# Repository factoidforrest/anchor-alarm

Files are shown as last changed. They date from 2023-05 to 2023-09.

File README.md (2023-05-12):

# Anchor Alarm

This is a DIY anchor alarm. An anchor alarm is a device that beeps if you take it further than the set distance from where you turned it on, to tell you if your anchor is dragging and you need to wake up before you run aground.

It is designed to run on the Esp32.

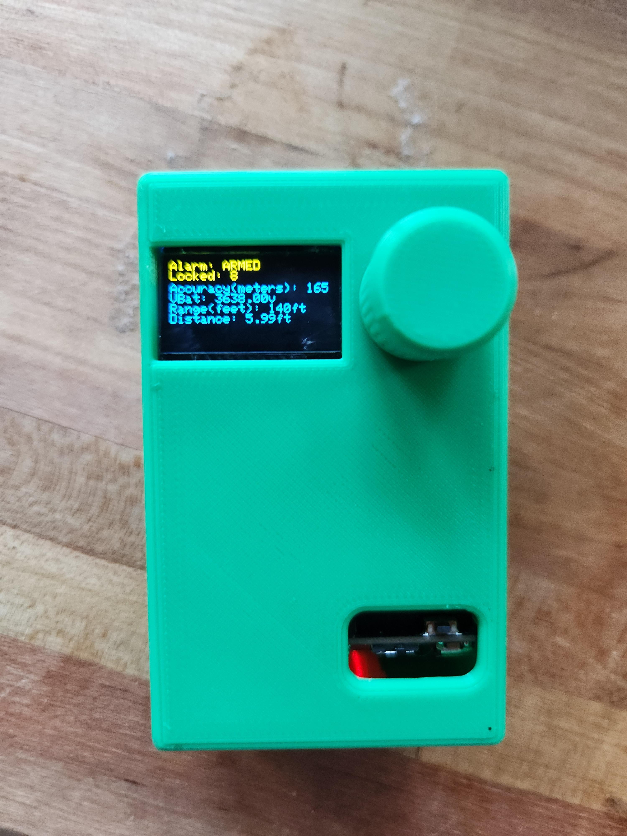
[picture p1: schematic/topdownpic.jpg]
top down pic of the thing in a case


## Hardware

* Mainboard: I ran it on the Esp32-c3 LilyGo OI plus, which is a compact form factor esp32 with an integrated battery slot and USB-C charging. This project could easily be adapted to other boards.

* GPS: I used a compact neo-8m GPS but this could be adapted to virtually any GPS with no code change. Anything supported by tinygpsplus

* Display 1306 .96in display

* Rotary encoder: Just about any with a button will do. 

* A buzzer. I used a magnetic, non self-oscillating buzzer. Small ones are better because they don't overpower the board and require other electronics like flyback diodes. You could also use a breakout board based buzzer, with those diodes incorporated. That would probably be safer for the esp32 and perhaps even louder. The small buzzer I used is just loud enough to be useful, but could easily be drowned out by, say, a loud fan.

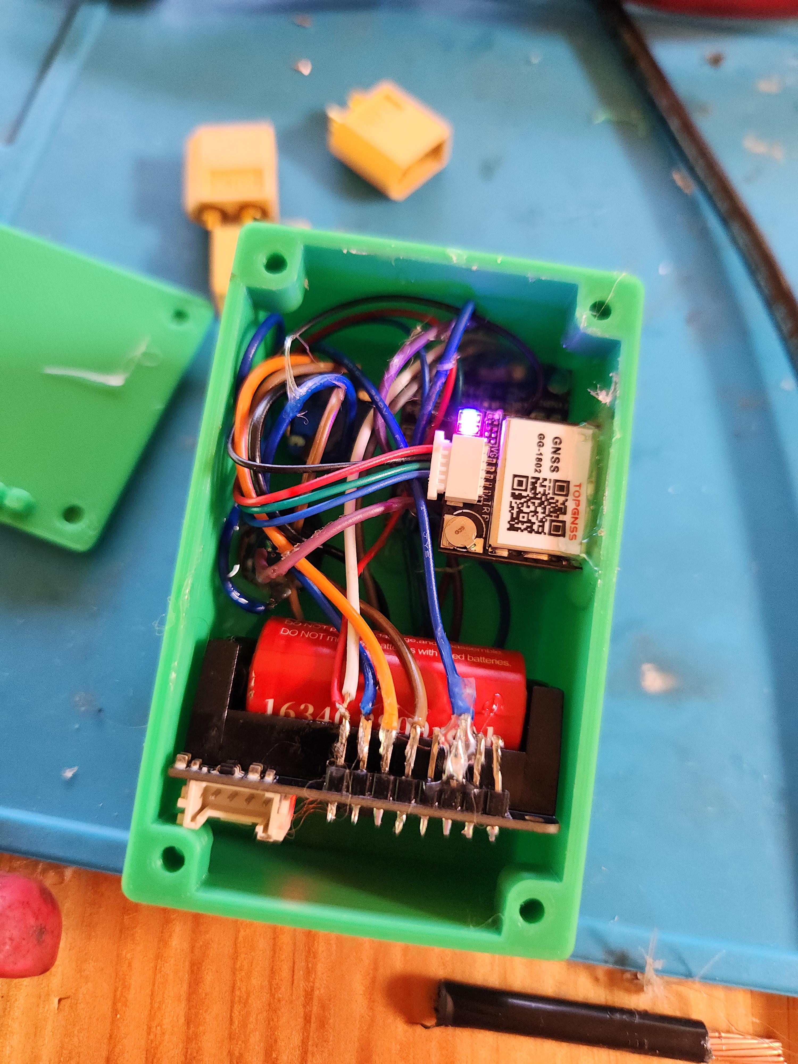
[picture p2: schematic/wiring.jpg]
wiring pic


## 3d Printed Case

If you match the above hardware including the mainboard, you can use my 3d printed case. STL files are in the repo root.

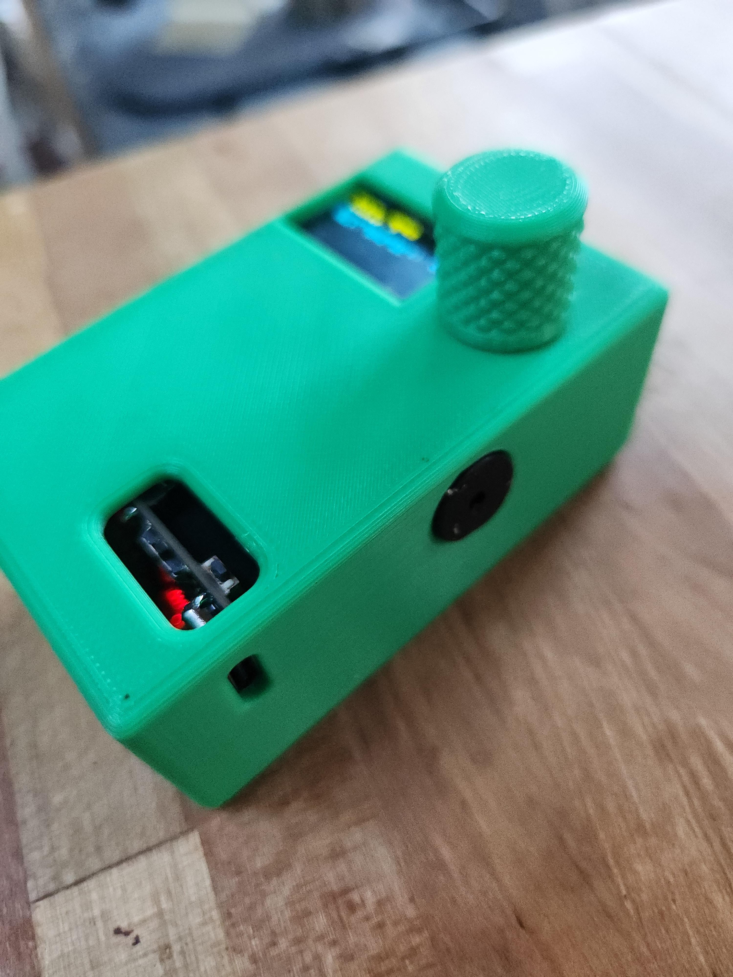
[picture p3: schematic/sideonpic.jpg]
case pic


## Software
Software has over-the-air update support: it creates a public wifi network for five minutes after boot. Hit 192.168.4.1/update to load new .bin firmware fil.

The device will alarm if it runs out of battery, loses the lock for over 10 seconds, or loses communications with the GPS.  

Only token attempts have been made to improve battery life.  It could probably be improved significantly by putting the GPS/esp32 to sleep for appropriate intervals, but that's easier said than done. It appears to only last about 5 hours at present, and so should be plugged in overnight to your phone charger on the boat.

See src/main.cpp for the sketch. Other files are simply tests/ scratchpads I used for debugging. There's also a lot of extra files in here because this was forked from the LilyGo sample project, since this board is nonstandard and needs a lot of custom stuff for the firmware to compile. Standard esp32s wont need that, you can just take the main.cpp sketch file.

### Compilation

This project is compiled by platformio. It will handle all library fetching. Change the board target if you're using a different esp32 version or 8266.

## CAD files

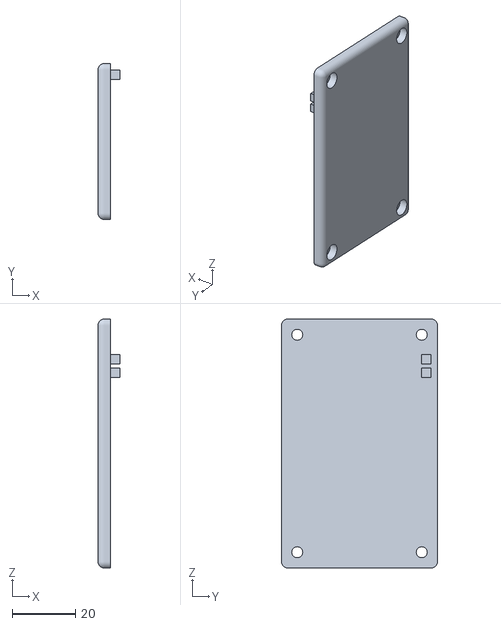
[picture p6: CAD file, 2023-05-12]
bottomlidwider.stl
7.00 x 49.5 x 79.0

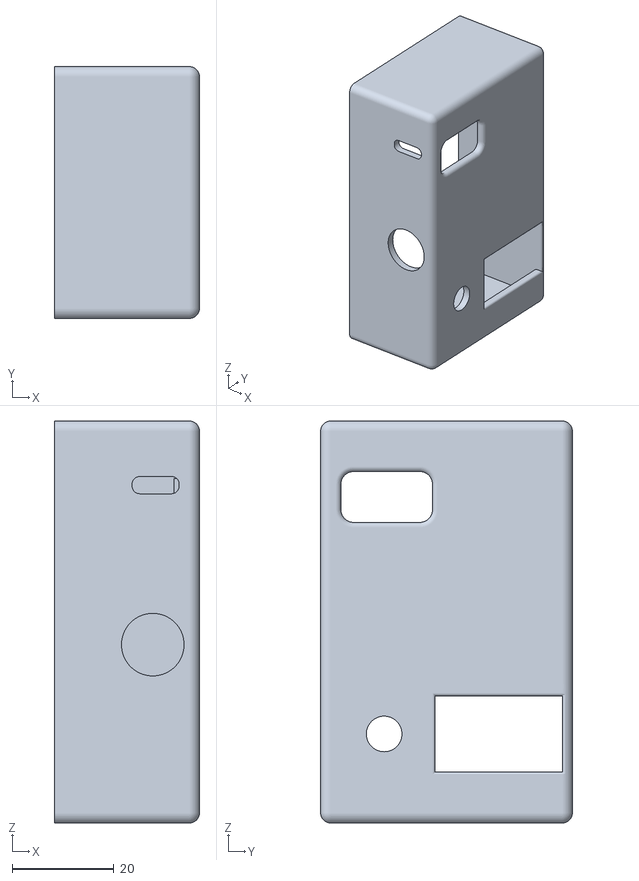
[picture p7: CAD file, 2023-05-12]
basewithole.stl
28.5 x 49.5 x 79.0

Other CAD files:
T-OI_Plus.dwg

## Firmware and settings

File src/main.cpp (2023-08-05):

#include <TinyGPSPlus.h>
#include <ezButton.h>
#include <WiFi.h>
#include <Wire.h>
#include <Adafruit_GFX.h>
#include <Adafruit_SSD1306.h>
#include "esp_adc_cal.h"
#include <pwmWrite.h>
#include <AsyncElegantOTA.h>
#include <AsyncTCP.h>
#include <ESPAsyncWebServer.h>
#include <LoRa.h>

#define SCREEN_WIDTH 128 // OLED display width, in pixels
#define SCREEN_HEIGHT 64 // OLED display height, in pixels

// Declaration for an SSD1306 display connected to I2C (SDA, SCL pins)
Adafruit_SSD1306 display(SCREEN_WIDTH, SCREEN_HEIGHT, &Wire, -1);

#define GPS_BAUD 9600
#define MYPORT_TX 12
#define MYPORT_RX 13

#define ROTARY_PIN_A 6
#define ROTARY_PIN_B 7
#define ROTARY_PIN_BTN 10

#define BUZZER_PIN 4
#define BUZZER_PWM_CHANNEL 0
#define BUZZER_PWM_FREQUENCY 1000
#define BUZZER_PWM_RESOLUTION 8

#define MAX_DISTANCE_FT 2000 // maximum allowable distance

Pwm pwm = Pwm();

TinyGPSTime lastGpsLock = TinyGPSTime();

TinyGPSPlus gps;

double anchor_lat, anchor_lng;
bool is_armed = false;
ezButton button(10); 

#define BAT_ADC    2

float Voltage = 0.0;

// this is for the vbat
uint32_t readADC_Cal(int ADC_Raw)
{
    esp_adc_cal_characteristics_t adc_chars;

    esp_adc_cal_characterize(ADC_UNIT_1, ADC_ATTEN_DB_11, ADC_WIDTH_BIT_12, 1100, &adc_chars);
    return (esp_adc_cal_raw_to_voltage(ADC_Raw, &adc_chars));
}

AsyncWebServer server(80);

void enableOTAUpdate() {
  WiFi.mode(WIFI_AP);

  WiFi.softAP("AnchorAlarmOTA");


  server.on("/", HTTP_GET, [](AsyncWebServerRequest *request) {
    request->send(200, "text/plain", "Hi! Head to /update to update the firmware. Use a .bin file from platformio build output");
  });
  
  AsyncElegantOTA.begin(&server);    // Start AsyncElegantOTA
  server.begin();
}

u_int32_t startupTime = millis();
bool serverOn = true;

u_int32_t lastTouchedTime = millis();

int alarm_range = 250;

void read_encoder() {
  // cli();
  // Encoder interrupt routine for both pins. Updates counter
  // if they are valid and have rotated a full indent
 
  static uint8_t old_AB = 3;  // Lookup table index
  static int8_t encval = 0;   // Encoder value  
  static const int8_t enc_states[]  = {0,-1,1,0,1,0,0,-1,-1,0,0,1,0,1,-1,0}; // Lookup table

  old_AB <<=2;  // Remember previous state

  if (digitalRead(ROTARY_PIN_A)) old_AB |= 0x02; // Add current state of pin A
  if (digitalRead(ROTARY_PIN_B)) old_AB |= 0x01; // Add current state of pin B
  
  encval += enc_states[( old_AB & 0x0f )];

  // Update counter if encoder has rotated a full indent, that is at least 4 steps
  if( encval > 3 ) {        // Four steps forward
    alarm_range += 5;              // Increase counter
    encval = 0;
  }
  else if( encval < -3 ) {  // Four steps backwards
   alarm_range -=5;               // Decrease counter
   encval = 0;
  }
  // sei();
  lastTouchedTime = millis();
}

void setup() {
    Serial.begin(9600);

    enableOTAUpdate();

    lastTouchedTime = millis();

    // esp_sleep_enable_uart_wakeup(0);
    // gpio_wakeup_enable(GPIO_NUM_6, GPIO_INTR_LOW_LEVEL);
    // gpio_wakeup_enable(GPIO_NUM_7, GPIO_INTR_LOW_LEVEL);
    // gpio_wakeup_enable(GPIO_NUM_10, GPIO_INTR_LOW_LEVEL);

    // esp_sleep_enable_gpio_wakeup();

    pinMode(ROTARY_PIN_A, INPUT_PULLUP);
    pinMode(ROTARY_PIN_B, INPUT_PULLUP);
    attachInterrupt(digitalPinToInterrupt(ROTARY_PIN_A), read_encoder, CHANGE);
    attachInterrupt(digitalPinToInterrupt(ROTARY_PIN_B), read_encoder, CHANGE);

    pinMode(ROTARY_PIN_BTN, INPUT_PULLUP);
    button.setDebounceTime(50); // set debounce time to 50 milliseconds

    Voltage = (readADC_Cal(analogRead(BAT_ADC))) * 2 ;

    display.begin(SSD1306_SWITCHCAPVCC, 0x3C);
    display.clearDisplay();

    display.setTextSize(1);
    display.setTextColor(WHITE);
    display.setCursor(0, 0);
    // Display static text
    display.println("Startup, waiting for GPS...");
    
    display.println(String("VBat: " + String(Voltage) + "v").c_str());
    display.display(); 

}

double calculateBearing(double lat1, double long1, double lat2, double long2) {
  lat1 = lat1 * (M_PI / 180);
  long1 = long1 * (M_PI / 180);
  lat2 = lat2 * (M_PI / 180);
  long2 = long2 * (M_PI / 180);

  double dLon = (long2 - long1);
  double x = cos(lat2) * sin(dLon);
  double y = cos(lat1) * sin(lat2) - sin(lat1) * cos(lat2) * cos(dLon);

  double bearing = atan2(x, y);
  bearing = bearing * (180 / M_PI);
  bearing = (int)(bearing + 360) % 360;

  return bearing;
}

String cardinalDirection(double bearing) {
  const char* directions[] = {"N", "NNE", "NE", "ENE", "E", "ESE", "SE", "SSE", "S", "SSW", "SW", "WSW", "W", "WNW", "NW", "NNW"};
  int index = (int)((bearing + 11.25) / 22.5) % 16;
  return directions[index];
}


void displayGPS() {
  display.clearDisplay();
  display.setCursor(0, 0);
  display.println(String("Alarm: " + String(is_armed ? "ARMED" : "Disarmed")).c_str());
  display.println("Locked: " + String(gps.satellites.value()));
  display.println("Accuracy(meters): " + String(gps.hdop.value()));

  display.println(String("VBat: " + String(Voltage) + "v").c_str());

  display.println(String("Range(feet): " + String(alarm_range) + "ft").c_str());

  if (is_armed) {
    double current_distance = TinyGPSPlus::distanceBetween( anchor_lat, anchor_lng, gps.location.lat(), gps.location.lng() );
    current_distance *= 3.281; // convert to feet

    double bearing = calculateBearing(anchor_lat, anchor_lng, gps.location.lat(), gps.location.lng());
    String direction = cardinalDirection(bearing);
    
    display.println(String("Dist: " + String(current_distance, 2) + "ft " + direction).c_str());

  }

  if (WiFi.getMode() != WIFI_OFF){
    display.println("Wifi On");
  }
  display.display();
}

void alarm(bool isOn){
  pwm.write(BUZZER_PIN, isOn ? 127 : 0, 2000);//2000, isOn ? 65535 : 0);
}

void checkDistance() {
  if (is_armed) {
    double current_distance = TinyGPSPlus::distanceBetween(gps.location.lat(), gps.location.lng(), anchor_lat, anchor_lng);
    current_distance *= 3.281; // convert to feet
      if (current_distance > alarm_range) {
      alarm(true);
    } else if (Voltage < 3400) {
      alarm(true);
    } else {
      alarm(false);
    }


  } else {
    alarm(false);
  }
}



void lockLost() {
  display.clearDisplay();
  display.setCursor(0,0);
  display.println("GPS Lock: No");
  display.println("Sattelites: " + String(gps.satellites.value()));

  display.display();
  if (is_armed) {
    alarm(true);
  }
}

void handleDisplaySleep(){

  if ((millis() - lastTouchedTime) > 120000){
    display.ssd1306_command(SSD1306_DISPLAYOFF);
  } else {
    display.ssd1306_command(SSD1306_DISPLAYON);
  }
}

void handleWifiSleep(){
  // after 5 minutes shut off wifi
  if (serverOn && (millis() - startupTime) > 300000){
    serverOn = false;
    server.end();
    WiFi.mode( WIFI_OFF );
    btStop();
    // slow down the cpu, actual sleep is too hard but this is pretty good
    if (!setCpuFrequencyMhz(40)){
      setCpuFrequencyMhz(80);
    }
  }
}

void loop() {
  button.loop();
  
  handleDisplaySleep();

  handleWifiSleep();

  if (lastGpsLock.isValid() && lastGpsLock.age() > 10000 && is_armed){
    lockLost();
  }




  Voltage = (readADC_Cal(analogRead(BAT_ADC))) * 2 ;


  while (Serial.available() > 0){
    if (gps.encode(Serial.read())) {
      if (!gps.location.isValid() && lastGpsLock.age() > 10000) {
          lockLost();
      } else {
        lastGpsLock = gps.time;
        if (button.getCount() > 0) {
          lastTouchedTime = millis();
          button.resetCount();
          if (is_armed) {
            is_armed = false;
          } else {
            is_armed = true;
            anchor_lat = gps.location.lat();
            anchor_lng = gps.location.lng();
          }
        }
        displayGPS();
        checkDistance();
      }
    } else {
        display.clearDisplay();
        display.println("GPS Error");
    }
  }

}

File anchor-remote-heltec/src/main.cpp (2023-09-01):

#include <Wire.h>
#include <Adafruit_GFX.h>
#include <Adafruit_SSD1306.h>
#include <pins.h>
#include <LoraFunctions.h>
#include <AsyncElegantOTA.h>
#include <AsyncTCP.h>
#include <ESPAsyncWebServer.h>

#define SCREEN_WIDTH 128 // OLED display width, in pixels
#define SCREEN_HEIGHT 64 // OLED display height, in pixels

// Declaration for an SSD1306 display connected to I2C (SDA, SCL pins)
Adafruit_SSD1306 display(SCREEN_WIDTH, SCREEN_HEIGHT, &Wire, RST_OLED);

#define VBAT_PIN 1
#define VBAT_READ_CNTRL_PIN 37 // Heltec GPIO to toggle VBatt read connection …
// Also, take care NOT to have ADC read connection
// in OPEN DRAIN when GPIO goes HIGH
#define ADC_READ_STABILIZE 10 // in ms (delay from GPIO control and ADC connections times)

#define ALARM_PIN 40

float readBatLevel() {
  int analogValue = analogRead(VBAT_PIN);
  float voltage = 0.0041 * analogValue;
  return voltage;
}


AsyncWebServer server(80);

void enableOTAUpdate() {
  WiFi.mode(WIFI_AP);

  WiFi.softAP("AnchorAlarmRemoteOTA");


  server.on("/", HTTP_GET, [](AsyncWebServerRequest *request) {
    request->send(200, "text/plain", "Hi! Head to /update to update the firmware. Use a .bin file from platformio build output");
  });
  
  AsyncElegantOTA.begin(&server);    // Start AsyncElegantOTA
  server.begin();
}

u_int32_t startupTime = millis();
bool serverOn = true;



void setup() {
  
  Serial.begin(115200);
  delay(5000);
  Serial.println("Booted");
  Wire.begin(SDA_OLED, SCL_OLED);

  enableOTAUpdate();

  // turn on vbat read
  pinMode(VBAT_READ_CNTRL_PIN, OUTPUT);
  digitalWrite(VBAT_READ_CNTRL_PIN, LOW);

  pinMode(ALARM_PIN, OUTPUT);
  pinMode(LED, OUTPUT);

  // initialize OLED
  delay(100);
  Serial.println("Awake");
  if(!display.begin(SSD1306_SWITCHCAPVCC, 0x3C)) { // Address 0x3D for 128x64
    Serial.println(F("SSD1306 allocation failed"));
    for(;;);
  }
  display.clearDisplay();

  display.setTextSize(1);
  display.setTextColor(WHITE);
  display.setCursor(0, 10);
  display.println("Starting...");
  display.display();
  bool lora_success = setup_lora();
  if (lora_success){
    display.println("Lora Chip Working");
  } else {
    display.println("Lora Chip Failure");
  }
  display.display();
  delay(500);

}


void setAlarm(bool alarmOn){
  Serial.println("setalarm called");
  if (alarmOn){
    Serial.println("Alarm on");
    digitalWrite(ALARM_PIN, LOW);
    digitalWrite(LED, HIGH);
  } else {
    digitalWrite(ALARM_PIN, HIGH);
    digitalWrite(LED, LOW);
  }
}

void handleWifiSleep(){
  // after 5 minutes shut off wifi
  if (serverOn && (millis() - startupTime) > 300000){
    serverOn = false;
    server.end();
    WiFi.mode( WIFI_OFF );
    btStop();
    // slow down the cpu, actual sleep is too hard but this is pretty good
    if (!setCpuFrequencyMhz(40)){
      setCpuFrequencyMhz(80);
    }
  }
}

String pBool(bool theBool){
  return theBool ? "True" : "False";
}

bool receivedPacketsPreviously = false;

void loop() {
  handleWifiSleep();

  display.clearDisplay();
  display.setCursor(0, 0); 

  ReceivedData received = receive_lora();
  if (received.error.length() > 0){
      // handle error
    display.println(received.error);
    if (receivedPacketsPreviously){
      setAlarm(true);
    }
  } else {
    receivedPacketsPreviously = true;
    setAlarm(received.alarm);
    display.println("Armed:" + pBool(received.armed) + " Lim:"  + String(received.limit));
    display.println("Alarm: " + pBool(received.alarm));
    display.println("Dist: " + String(received.distance) + " " + received.direction);
    display.println("RSSI: " + String(received.rssi) + " SNR: " + String(received.rssi));
  }

  float vbat = readBatLevel();
  display.println("Batt: " + String(vbat) + "v");
  if (vbat< 3.5){
    setAlarm(true);
    display.println("LOW BATTERY");
  } 

  display.display();
  delay(500);
}

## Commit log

2023-05-12 enable some power saving stuff
2023-08-06 prototyped out most of lora code
